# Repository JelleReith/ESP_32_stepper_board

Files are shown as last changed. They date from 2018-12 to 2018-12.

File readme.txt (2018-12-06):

Hi,
Thanks for using this board!

Hardware:
1 x ESP32 Devkit v1
9 x DRV8825 stepper driver
9 x 100uf 50v capacitor
pin_headers or screw terminals.

      //////////////////////BOARD LAYOUT\\\\\\\\\\\\\\\\\\\\\\\
      
 DIPDIP VESPVMOT  DRV0  DRV1  DRV2  DRV3  DRV4  DRV5  DRV6  DRV7  DRV8
 DIPDIP
ESPESPESPESPESP    CAP     DRV0DRV0DRV0  DRV5DRV5DRV5 CAP DRV6DRV6DRV6
ESPESPESPESPESP            DRV0DRV0DRV0  DRV5DRV5DRV5     DRV6DRV6DRV6
ESPESPESPESPESP            DRV0DRV0DRV0  DRV5DRV5DRV5 CAP DRV6DRV6DRV6
ESPESPESPESPESP
ESPESPESPESPESP    CAP     DRV1DRV1DRV1  DRV4DRV4DRV4 CAP DRV7DRV7DRV7
ESPESPESPESPESP            DRV1DRV1DRV1  DRV4DRV4DRV4     DRV7DRV7DRV7
ESPESPESPESPESP            DRV1DRV1DRV1  DRV4DRV4DRV4 CAP DRV7DRV7DRV7
ESPESPESPESPESP
ESPESPESPESPESP    CAP     DRV3DRV2DRV2  DRV3DRV3DRV3 CAP DRV8DRV8DRV8
ESPESPESPESPESP            DRV3DRV2DRV2  DRV3DRV3DRV3 CAP DRV8DRV8DRV8
ESPESPESPESPESP            DRV3DRV2DRV2  DRV3DRV3DRV3 CAP DRV8DRV8DRV8

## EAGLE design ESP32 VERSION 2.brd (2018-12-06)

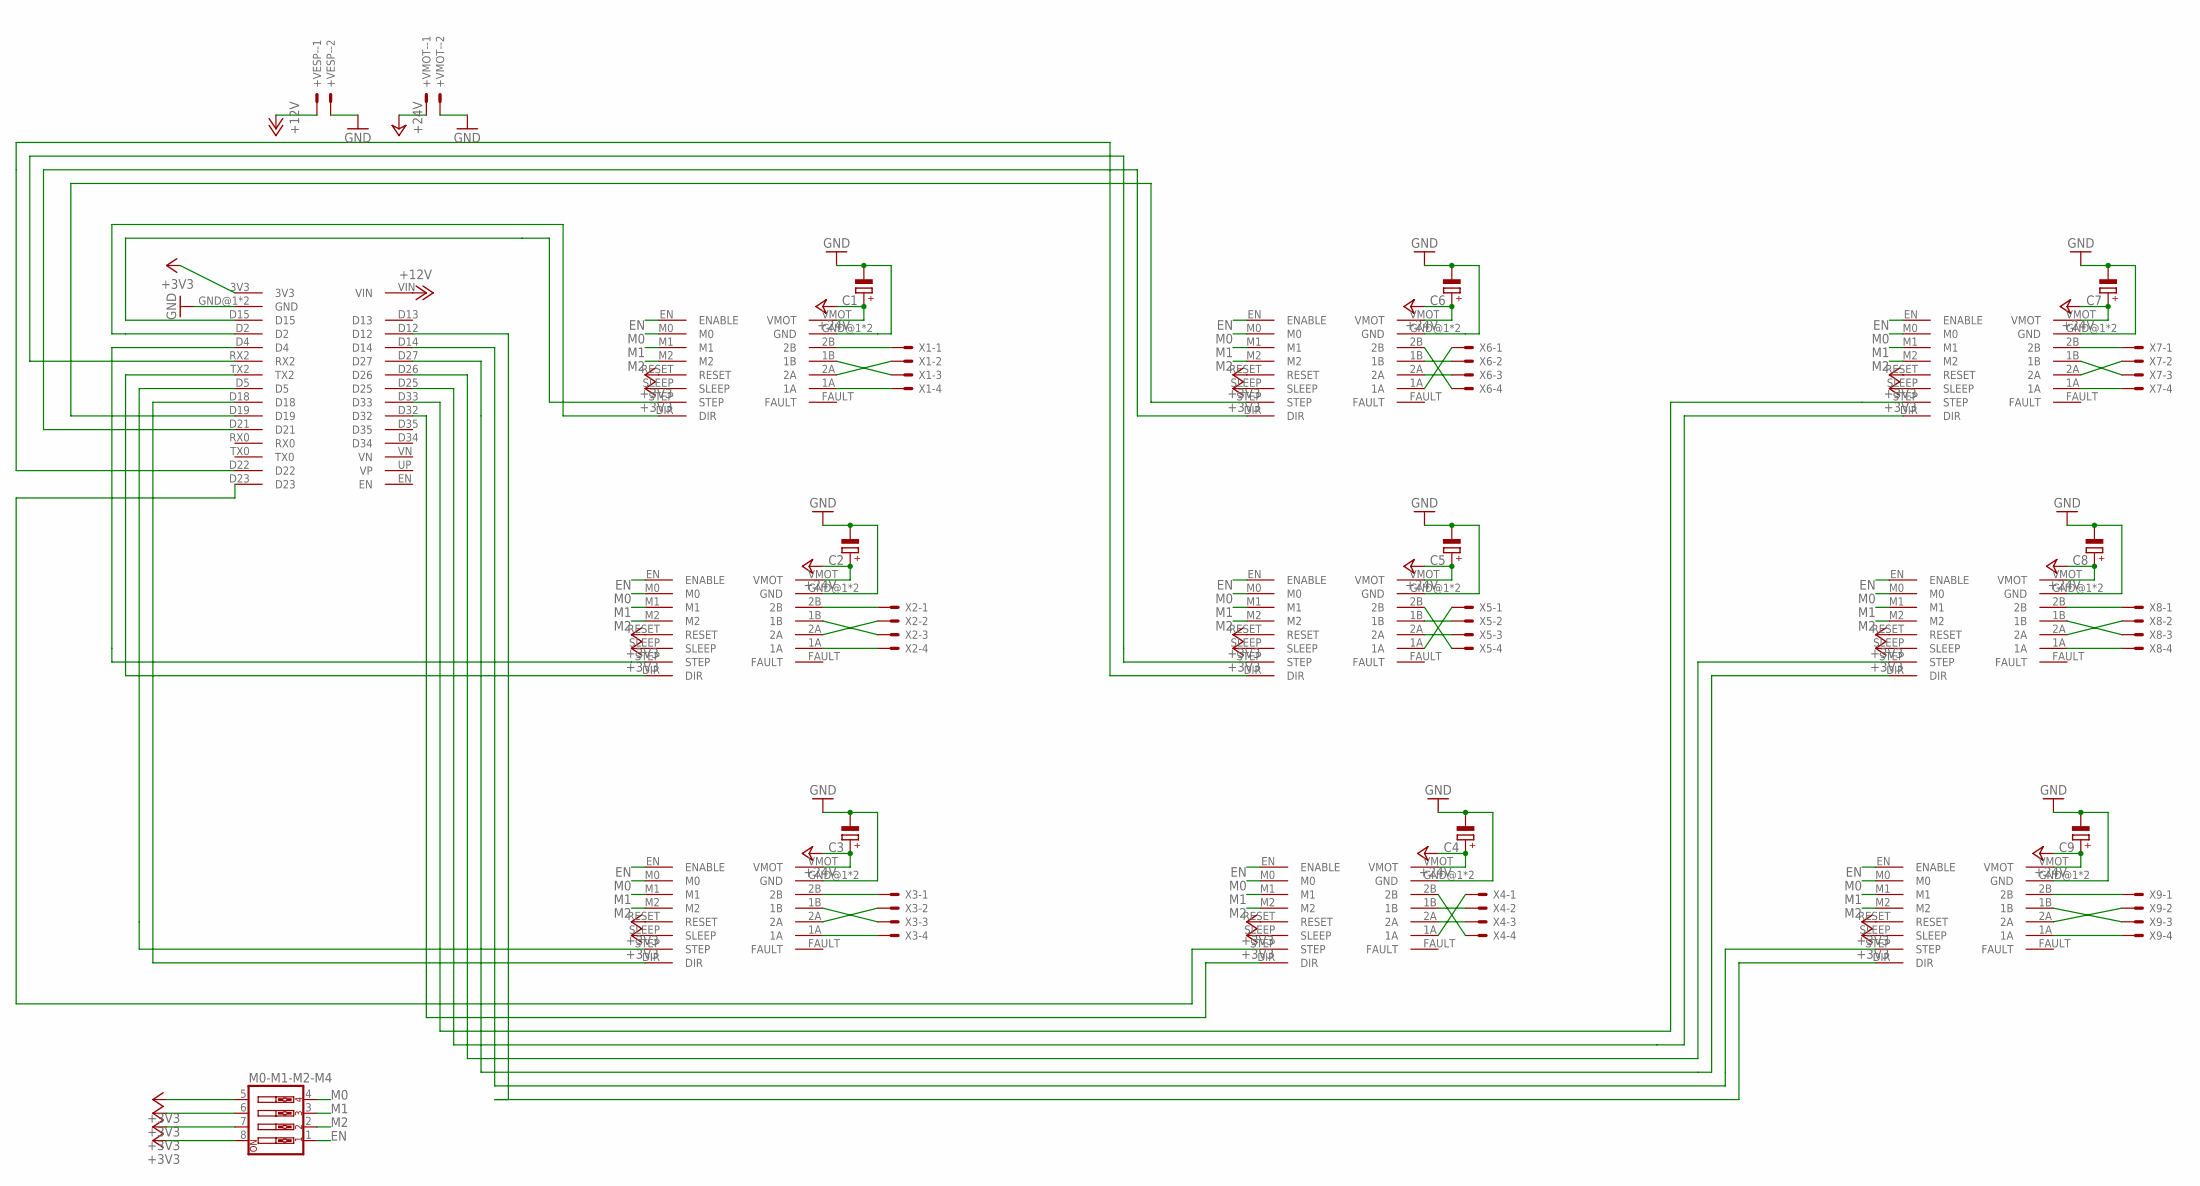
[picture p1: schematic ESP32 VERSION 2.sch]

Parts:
+VESP-: 22-23-2021
+VMOT-: 22-23-2021
C1, C2, C3, C4, C5, C6, C7, C8, C9: CPOL-EUE3.5-8; E3,5-8
M0-M1-M2-M4: SW_DIP-4; EDG-04
U$1, U$2, U$4, U$5, U$6, U$7, U$8, U$9: DRV8825
U$3: STEPPER 0; DRV8825
U$10: ESP32
X1, X2, X3, X4, X5, X6, X7, X8, X9: 22-23-2041

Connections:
+3V3: M0-M1-M2-M4.5, M0-M1-M2-M4.6, M0-M1-M2-M4.7, M0-M1-M2-M4.8, U$1.RESET, U$1.SLEEP, U$2.RESET, U$2.SLEEP, U$3.RESET, U$3.SLEEP, U$4.RESET, U$4.SLEEP, U$5.RESET, U$5.SLEEP, U$6.RESET, U$6.SLEEP, U$7.RESET, U$7.SLEEP, U$8.RESET, U$8.SLEEP, U$9.RESET, U$9.SLEEP, U$10.3V3
+12V: +VESP-.1, U$10.VIN
+24V: +VMOT-.1, C1.+, C2.+, C3.+, C4.+, C5.+, C6.+, C7.+, C8.+, C9.+, U$1.VMOT, U$2.VMOT, U$3.VMOT, U$4.VMOT, U$5.VMOT, U$6.VMOT, U$7.VMOT, U$8.VMOT, U$9.VMOT
EN: M0-M1-M2-M4.1, U$1.EN (ENABLE), U$2.EN (ENABLE), U$3.EN (ENABLE), U$4.EN (ENABLE), U$5.EN (ENABLE), U$6.EN (ENABLE), U$7.EN (ENABLE), U$8.EN (ENABLE), U$9.EN (ENABLE)
GND: +VESP-.2, +VMOT-.2, C1.-, C2.-, C3.-, C4.-, C5.-, C6.-, C7.-, C8.-, C9.-, U$1.GND@1 (GND), U$1.GND@2 (GND), U$2.GND@1 (GND), U$2.GND@2 (GND), U$3.GND@1 (GND), U$3.GND@2 (GND), U$4.GND@1 (GND), U$4.GND@2 (GND), U$5.GND@1 (GND), U$5.GND@2 (GND), U$6.GND@1 (GND), U$6.GND@2 (GND), U$7.GND@1 (GND), U$7.GND@2 (GND), U$8.GND@1 (GND), U$8.GND@2 (GND), U$9.GND@1 (GND), U$9.GND@2 (GND), U$10.GND@1 (GND), U$10.GND@2 (GND)
M0: M0-M1-M2-M4.4, U$1.M0, U$2.M0, U$3.M0, U$4.M0, U$5.M0, U$6.M0, U$7.M0, U$8.M0, U$9.M0
M1: M0-M1-M2-M4.3, U$1.M1, U$2.M1, U$3.M1, U$4.M1, U$5.M1, U$6.M1, U$7.M1, U$8.M1, U$9.M1
M2: M0-M1-M2-M4.2, U$1.M2, U$2.M2, U$3.M2, U$4.M2, U$5.M2, U$6.M2, U$7.M2, U$8.M2, U$9.M2
unnamed: U$3.2B, X1.1
unnamed: U$9.1B, X9.3
unnamed: U$9.2A, X9.2
unnamed: U$3.1A, X1.4
unnamed: U$3.STEP, U$10.D15
unnamed: U$3.DIR, U$10.D2
unnamed: U$4.1A, X6.1
unnamed: U$4.2A, X6.3
unnamed: U$4.1B, X6.2
unnamed: U$4.2B, X6.4
unnamed: U$2.STEP, U$10.D4
unnamed: U$2.DIR, U$10.TX2
unnamed: U$7.2B, X7.1
unnamed: U$7.2A, X7.2
unnamed: U$7.1B, X7.3
unnamed: U$7.1A, X7.4
unnamed: U$1.STEP, U$10.D5
unnamed: U$2.2B, X2.1
unnamed: U$8.2B, X8.1
unnamed: U$8.1B, X8.3
unnamed: U$8.2A, X8.2
unnamed: U$8.1A, X8.4
unnamed: U$1.DIR, U$10.D18
unnamed: U$2.1B, X2.3
unnamed: U$9.2B, X9.1
unnamed: U$5.1B, X5.2
unnamed: U$5.2A, X5.3
unnamed: U$9.1A, X9.4
unnamed: U$4.DIR, U$10.D21
unnamed: U$2.2A, X2.2
unnamed: U$5.1A, X5.1
unnamed: U$5.2B, X5.4
unnamed: U$6.1B, X4.2
unnamed: U$6.2A, X4.3
unnamed: U$4.STEP, U$10.D19
unnamed: U$5.STEP, U$10.RX2
unnamed: U$6.2B, X4.4
unnamed: U$6.1A, X4.1
unnamed: U$1.1B, X3.3
unnamed: U$1.2A, X3.2
unnamed: U$5.DIR, U$10.D22
unnamed: U$2.1A, X2.4
unnamed: U$1.2B, X3.1
unnamed: U$3.1B, X1.3
unnamed: U$3.2A, X1.2
unnamed: U$1.1A, X3.4
unnamed: U$6.STEP, U$10.D23
unnamed: U$6.DIR, U$10.D32
unnamed: U$7.STEP, U$10.D33
unnamed: U$7.DIR, U$10.D25
unnamed: U$8.STEP, U$10.D26
unnamed: U$8.DIR, U$10.D27
unnamed: U$9.STEP, U$10.D14
unnamed: U$9.DIR, U$10.D12

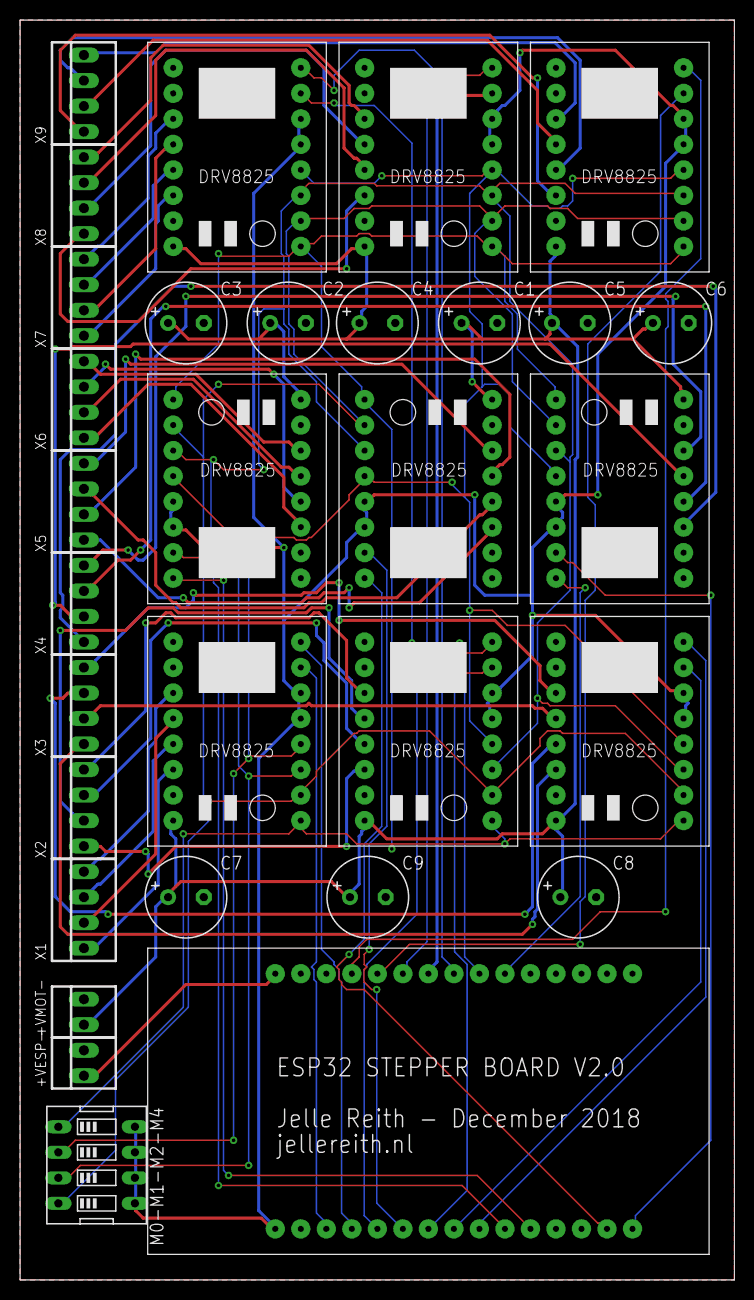
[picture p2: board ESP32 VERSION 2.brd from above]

Board: 2 copper layers, 71.1 x 125.4 mm, 31 parts (0 on the bottom side), 62 nets.

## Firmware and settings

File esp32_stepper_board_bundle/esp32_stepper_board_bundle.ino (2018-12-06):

#include <WiFi.h>
#include <WiFiUdp.h>
#include <OSCMessage.h>
#include <OSCBundle.h>
#include <OSCData.h>
#include <AccelStepper.h>

boolean debug = true; //if set to true Serial.println works but stepper

AccelStepper stepper0 (AccelStepper::DRIVER, 15, 2);
AccelStepper stepper1 (AccelStepper::DRIVER, 4, 17);
AccelStepper stepper2 (AccelStepper::DRIVER, 5, 18);
AccelStepper stepper3 (AccelStepper::DRIVER, 23, 32);
AccelStepper stepper4 (AccelStepper::DRIVER, 16, 22);// pin 3 on old board!
AccelStepper stepper5 (AccelStepper::DRIVER, 19, 21);
AccelStepper stepper6 (AccelStepper::DRIVER, 33, 25);
AccelStepper stepper7 (AccelStepper::DRIVER, 26, 27);
AccelStepper stepper8 (AccelStepper::DRIVER, 14, 12);

char ssid[] = "YOURSSID";               // your network SSID (name)
char pass[] = "YOURPSK";           // your network password

WiFiUDP Udp;
const IPAddress outIp(10, 40, 10, 105);     // remote IP (not needed for receive)
const unsigned int outPort = 9999;          // remote port (not needed for receive)
const unsigned int localPort = 8888;        // local port to listen for UDP packets (here's where we send the packets)

int pos0, pos1, pos2, pos3, pos4, pos5, pos6, pos7, pos8 = 0;
int accel0, accel1, accel2, accel3, accel4, accel5, accel6, accel7, accel8 = 0;
int speed0, speed1, speed2, speed3, speed4, speed5, speed6, speed7, speed8 = 0;
OSCErrorCode error;

int max_speed = 1000;
int my_speed = 1000;
int my_accel = 1500;

void setup() {

  stepper0.setMaxSpeed(max_speed);
  stepper0.setAcceleration(my_accel);

  stepper1.setMaxSpeed(max_speed);
  stepper1.setAcceleration(my_accel);

  stepper2.setMaxSpeed(max_speed);
  stepper2.setAcceleration(my_accel);

  stepper3.setMaxSpeed(max_speed);
  stepper3.setAcceleration(my_accel);

  stepper4.setMaxSpeed(max_speed);
  stepper4.setAcceleration(my_accel);

  stepper5.setMaxSpeed(max_speed);
  stepper5.setAcceleration(my_accel);

  stepper6.setMaxSpeed(max_speed);
  stepper6.setAcceleration(my_accel);

  stepper7.setMaxSpeed(max_speed);
  stepper7.setAcceleration(my_accel);

  stepper8.setMaxSpeed(max_speed);
  stepper8.setAcceleration(my_accel);
  if (debug) {
    Serial.begin(9600);
  }
  WiFi.begin(ssid, pass);
  while (WiFi.status() != WL_CONNECTED) {
    if (debug) {
      Serial.print(".");
    }
    delay(500);
  }
  if (debug) {
    Serial.println("");
    Serial.println("WiFi connected");
    Serial.println("IP address: ");
    Serial.println(WiFi.localIP());
    Serial.println("Starting UDP");
  }
  Udp.begin(localPort);
  if (debug) {
    Serial.print("Local port: ");
  }
#ifdef ESP32
  if (debug) {
    Serial.println(localPort);
  }
#else
  if (debug) {
    Serial.println(Udp.localPort());
  }
#endif

}
void accels(OSCMessage &msg) {
  accel0 = msg.getInt(0);
  accel1 = msg.getInt(1);
  accel2 = msg.getInt(2);
  accel3 = msg.getInt(3);
  accel4 = msg.getInt(4);
  accel5 = msg.getInt(5);
  accel6 = msg.getInt(6);
  accel7 = msg.getInt(7);
  accel8 = msg.getInt(8);

  stepper0.setAcceleration(accel0);
  stepper1.setAcceleration(accel1);
  stepper2.setAcceleration(accel2);
  stepper3.setAcceleration(accel3);
  stepper4.setAcceleration(accel4);
  stepper5.setAcceleration(accel5);
  stepper6.setAcceleration(accel6);
  stepper7.setAcceleration(accel7);
  stepper8.setAcceleration(accel8);


  if (debug) {
    Serial.print("accel 0 : " );
    Serial.println(accel0);
    Serial.print("accel 1 : " );
    Serial.println(accel1);
    Serial.print("accel 2 : " );
    Serial.println(accel2);
    Serial.print("accel 3 : " );
    Serial.println(accel3);
    Serial.print("accel 4 : " );
    Serial.println(accel4);
    Serial.print("accel 5 : " );
    Serial.println(accel5);
    Serial.print("accel 6 : " );
    Serial.println(accel6);
    Serial.print("accel 7 : " );
    Serial.println(accel7);
    Serial.print("accel 8 : " );
    Serial.println(accel8);
  }
}

void speeds(OSCMessage &msg) {
    speed0 = msg.getInt(0);
  speed1 = msg.getInt(1);
  speed2 = msg.getInt(2);
  speed3 = msg.getInt(3);
  speed4 = msg.getInt(4);
  speed5 = msg.getInt(5);
  speed6 = msg.getInt(6);
  speed7 = msg.getInt(7);
  speed8 = msg.getInt(8);

  stepper0.setSpeed(speed0);
  stepper1.setSpeed(speed1);
  stepper2.setSpeed(speed2);
  stepper3.setSpeed(speed3);
  stepper4.setSpeed(speed4);
  stepper5.setSpeed(speed5);
  stepper6.setSpeed(speed6);
  stepper7.setSpeed(speed7);
  stepper8.setSpeed(speed8);


  if (debug) {
    Serial.print("speed 0 : " );
    Serial.println(speed0);
    Serial.print("speed 1 : " );
    Serial.println(speed1);
    Serial.print("speed 2 : " );
    Serial.println(speed2);
    Serial.print("speed 3 : " );
    Serial.println(speed3);
    Serial.print("speed 4 : " );
    Serial.println(speed4);
    Serial.print("speed 5 : " );
    Serial.println(speed5);
    Serial.print("speed 6 : " );
    Serial.println(speed6);
    Serial.print("speed 7 : " );
    Serial.println(speed7);
    Serial.print("speed 8 : " );
    Serial.println(speed8);
  }
}

void steppers(OSCMessage &msg) {
  pos0 = msg.getInt(0);
  pos1 = msg.getInt(1);
  pos2 = msg.getInt(2);
  pos3 = msg.getInt(3);
  pos4 = msg.getInt(4);
  pos5 = msg.getInt(5);
  pos6 = msg.getInt(6);
  pos7 = msg.getInt(7);
  pos8 = msg.getInt(8);

  stepper0.moveTo(pos0);
  stepper1.moveTo(pos1);
  stepper2.moveTo(pos2);
  stepper3.moveTo(-pos3);
  stepper4.moveTo(-pos4);
  stepper5.moveTo(-pos5);
  stepper6.moveTo(pos6);
  stepper7.moveTo(pos7);
  stepper8.moveTo(pos8);
  if (debug) {
    Serial.print("stepper 0 : " );
    Serial.println(pos0);
    Serial.print("stepper 1 : " );
    Serial.println(pos1);
    Serial.print("stepper 2 : " );
    Serial.println(pos2);
    Serial.print("stepper 3 : " );
    Serial.println(pos3);
    Serial.print("stepper 4 : " );
    Serial.println(pos4);
    Serial.print("stepper 5 : " );
    Serial.println(pos5);
    Serial.print("stepper 6 : " );
    Serial.println(pos6);
    Serial.print("stepper 7 : " );
    Serial.println(pos7);
    Serial.print("stepper 8 : " );
    Serial.println(pos8);
  }
}

void loop() {
  stepper0.run();
  stepper1.run();
  stepper2.run();
  stepper3.run();
  stepper4.run();
  stepper5.run();
  stepper6.run();
  stepper7.run();
  stepper8.run();

  OSCBundle bundle;
  int size = Udp.parsePacket();

  if (size > 0) {
    while (size--) {
      bundle.fill(Udp.read());
    }
    if (!bundle.hasError()) {
      bundle.dispatch("/accels", accels);
      bundle.dispatch("/speeds", speeds);
      bundle.dispatch("/steppers", steppers);
    } else {
      error = bundle.getError();
    }
  }
}

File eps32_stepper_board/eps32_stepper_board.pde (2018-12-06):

import oscP5.*;
import netP5.*;
import controlP5.*;

ControlP5 cp5;

OscP5 oscP5;
NetAddress myRemoteLocation;


int stepper0 = 0;
int stepper1 = 0;
int stepper2 = 0;
int stepper3 = 0;
int stepper4 = 0;
int stepper5 = 0;
int stepper6 = 0;
int stepper7 = 0;
int stepper8 = 0;

int minStep = -400; 
int maxStep = 400;

void setup() {
  size(800, 800);
  background(0);
  strokeWeight(3);
  stroke(255);
  oscP5 = new OscP5(this, 12000);
  myRemoteLocation = new NetAddress("192.168.178.23", 8888); //IP of the ESP!

  cp5 = new ControlP5(this);

  cp5.addSlider("stepper0")
    .setPosition(20, 20)
    .setSize(200, 20)
    .setRange(minStep, maxStep)
    ;

  cp5.addSlider("stepper1")
    .setPosition(20, 120)
    .setSize(200, 20)
    .setRange(minStep, maxStep)
    ;

  cp5.addSlider("stepper2")
    .setPosition(20, 220)
    .setSize(200, 20)
    .setRange(minStep, maxStep)
    ;

  cp5.addSlider("stepper3")
    .setPosition(220, 20)
    .setSize(200, 20)
    .setRange(minStep, maxStep)
    ;

  cp5.addSlider("stepper4")
    .setPosition(220, 120)
    .setSize(200, 20)
    .setRange(minStep, maxStep)
    ;

  cp5.addSlider("stepper5")
    .setPosition(220, 220)
    .setSize(200, 20)
    .setRange(minStep, maxStep)
    ;

  cp5.addSlider("stepper6")
    .setPosition(420, 20)
    .setSize(200, 20)
    .setRange(minStep, maxStep)
    ;

  cp5.addSlider("stepper7")
    .setPosition(420, 120)
    .setSize(200, 20)
    .setRange(minStep, maxStep)
    ;

  cp5.addSlider("stepper8")
    .setPosition(420, 220)
    .setSize(200, 20)
    .setRange(minStep, maxStep)
    ;
  send_accel(100);
  send_speed(200);
  send_pos();
}


void draw() {
}

void mouseReleased() {
  send_pos();
}

void send_speed(int sp0) {
  OscMessage speeds = new OscMessage("/speed");
  speeds.add(sp0);
  oscP5.send(speeds, myRemoteLocation);
}

void send_accel(int ac0) {
  OscMessage accels = new OscMessage("/accel");
  accels.add(ac0);
  oscP5.send(accels, myRemoteLocation);
}

void send_pos() {
  OscMessage stepper0_pos = new OscMessage("/stepper0");
  stepper0_pos.add(stepper0);
  oscP5.send(stepper0_pos, myRemoteLocation);

  OscMessage stepper1_pos = new OscMessage("/stepper1");
  stepper1_pos.add(stepper1);
  oscP5.send(stepper1_pos, myRemoteLocation);

  OscMessage stepper2_pos = new OscMessage("/stepper2");
  stepper2_pos.add(stepper2);
  oscP5.send(stepper2_pos, myRemoteLocation);

  OscMessage stepper3_pos = new OscMessage("/stepper3");
  stepper3_pos.add(stepper3);
  oscP5.send(stepper3_pos, myRemoteLocation);

  OscMessage stepper4_pos = new OscMessage("/stepper4");
  stepper4_pos.add(stepper4);
  oscP5.send(stepper4_pos, myRemoteLocation);

  OscMessage stepper5_pos = new OscMessage("/stepper5");
  stepper5_pos.add(stepper5);
  oscP5.send(stepper5_pos, myRemoteLocation);

  OscMessage stepper6_pos = new OscMessage("/stepper6");
  stepper6_pos.add(stepper6);
  oscP5.send(stepper6_pos, myRemoteLocation);

  OscMessage stepper7_pos = new OscMessage("/stepper7");
  stepper7_pos.add(stepper7);
  oscP5.send(stepper7_pos, myRemoteLocation);

  OscMessage stepper8_pos = new OscMessage("/stepper8");
  stepper8_pos.add(stepper8);
  oscP5.send(stepper8_pos, myRemoteLocation);
}

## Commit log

2018-12-06 Add files via upload
    Software for EPS and processing sketch
    Libraries arduino:
    Accelstepper: https://www.airspayce.com/mikem/arduino/AccelStepper/
    OSC: https://github.com/CNMAT/OSC
2018-12-06 Add files via upload
    EAGLE files
    [ESP32 VERSION 2.brd, ESP32 VERSION 2.sch]
